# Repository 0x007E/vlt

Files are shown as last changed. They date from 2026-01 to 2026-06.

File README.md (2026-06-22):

  

# `VLT` - Data Vault

The `VLT` is a board with an [RNG90](#additional-information) and a `TRNG` based on a digital circuit. It is possible to generate random numbers and print them over `UART`. The board itself is driven with `5V` over a `USBC` connector. The board itself can be programmed over `USB` and `avr-dude` (`serialupdi`). To programm the board over `USB` (`UART`) it is necessary to enable the `UPDI` programming function (over the onboard dip-switches). 

| Experience  | Level |
|:---|:---:|
| Soldering | ?% |
| Mechanical  | ?% |

# Downloads

| Type | File | Description |
|:---:|:---:|:---|
| Schematic | [pdf](https://github.com/0x007E/vlt/releases/latest/download/schematic.pdf) / [cadlab](https://cadlab.io/project/29805/main/files) | Schematic files |
| Board | [pdf](https://github.com/0x007E/vlt/releases/latest/download/pcb.pdf) / [cadlab](https://cadlab.io/project/29805/main/files) | Board file |
| Drill | [pdf](https://github.com/0x007E/vlt/releases/latest/download/drill.pdf) | Drill file |
| BoM | [xlsx](https://github.com/0x007E/vlt/releases/latest/download/bom.xlsx) / [html](https://github.com/0x007E/vlt/releases/latest/download/ibom.html) | Bill of Material as Excel/interactive HTML |
| PCB | [zip](https://github.com/0x007E/vlt/releases/latest/download/kicad.zip) / [tar](https://github.com/0x007E/vlt/releases/latest/download/kicad.tar.gz) | KiCAD/Gerber/BoM/Drill files |
| Mechanical | [zip](https://github.com/0x007E/vlt/releases/latest/download/freecad.zip) / [tar](https://github.com/0x007E/vlt/releases/latest/download/freecad.tar.gz) | FreeCAD/Housing and PCB (STEP/STL) files |

# Hardware

The pcb is created with `KiCAD`, the housing with `FreeCAD`. All files are built with `github actions` so that they are ready for a production environment.

## PCB

The circuit board is populated on both sides (Top, Bottom). The best way for soldering the `SMD` components is within a vapor phase soldering system and for the `THT` components with a standard soldering system.

### Top Layer

Top Layer

### Bottom Layer

Bottom Layer

## Mechanical

The housing has a tolerance of `0.2mm` on each side of the case. So the pcb should fit perfectly in the housing. The tolerance can be modified with `FreeCAD` in the `Parameter` Spreadsheet.

### Assembled

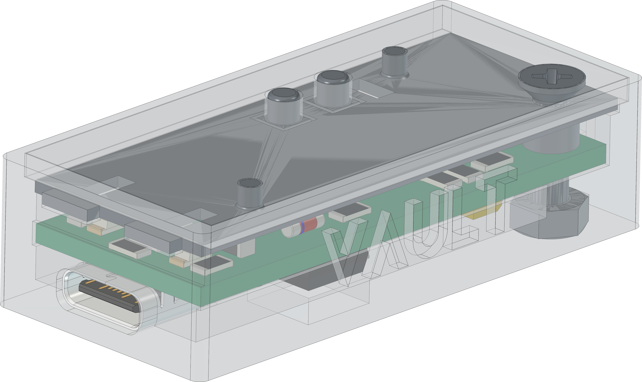
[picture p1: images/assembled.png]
Assembled


### Exploded

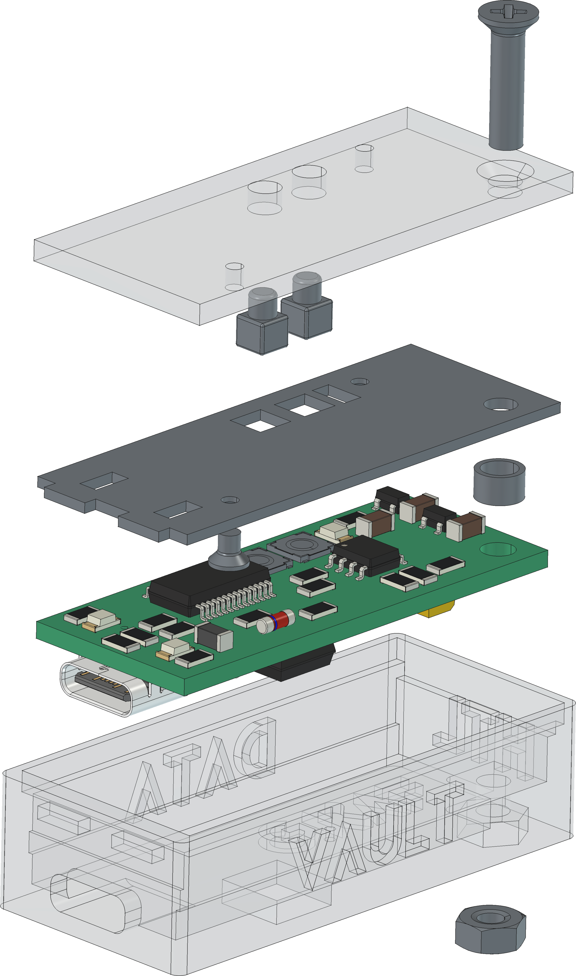
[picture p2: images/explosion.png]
Exploded


# Additional Information

| Type | Link | Description |
|:---:|:---:|:---|
| FT232RL | [pdf](https://ftdichip.com/wp-content/uploads/2020/08/DS_FT232R.pdf) | USB Full Speed to Serial UART IC, Includes Oscillator and EEPROM |
| RNG90 | [pdf](https://ww1.microchip.com/downloads/aemDocuments/documents/SCBU/ProductDocuments/DataSheets/RNG90-CryptoAuthentication-Data-Sheet-DS40002499.pdf) | RNG90 CryptoAuthentication |

---

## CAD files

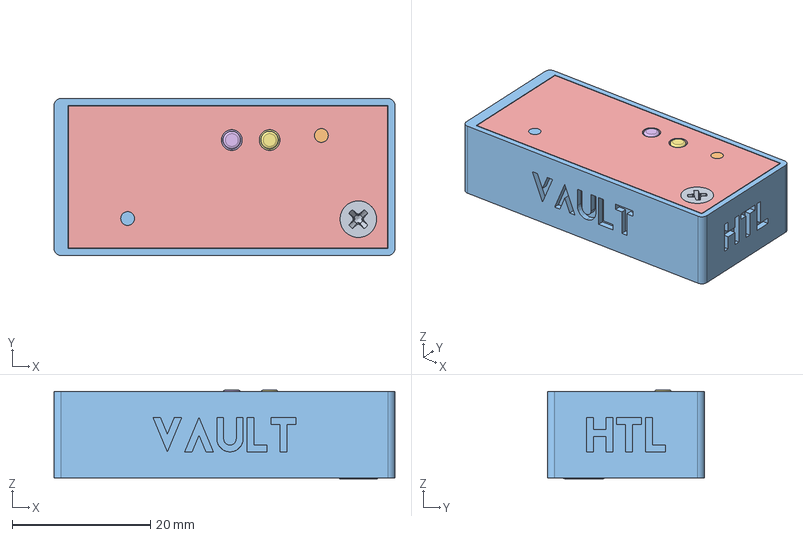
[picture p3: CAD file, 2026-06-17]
mechanical/housing.FCStd
49.3 x 22.7 x 12.8 mm
Pcb_bebe
R1_R_1206_3216Metric_f603423b577c
R5_R_1206_3216Metric_7a7bcd21324c
FB1_L_1206_3216Metric_6fcd3b987292
R15_R_1206_3216Metric_929cc7beda6f
R7_R_1206_3216Metric_0ce5cb771788
R9_R_1206_3216Metric_481f4e21f800
SW1_1_4773eb2bfa41
R17_R_1206_3216Metric_f1ba10fde7b4
D5_LED_1206_3216Metric_f05a8198d155
R4_R_1206_3216Metric_d46e669ba6ba
D3_LED_1206_3216Metric_8bff945b0123
U5_SOT-23-5_21eb59ce2435
R10_R_1206_3216Metric_805d08f095cc
D4_LED_1206_3216Metric_23e95f824b67
R3_R_1206_3216Metric_152a8680d59a
R2_R_1206_3216Metric_31ec9ef0ca55
SW2_1_7b24997decc5
D2_D_MiniMELF_Standard_88843ffb6f9b
C7_C_1206_3216Metric_addbe9d90b21
R6_R_1206_3216Metric_e929d92d168d
R16_R_1206_3216Metric_9d2ac8d5d94a
U6_SOT-23-5_1ebc3b3ece8a
U4_SOIC-8_3.9x4.9mm_P1.27mm_29fbfb699674
R18_R_1206_3216Metric_19b3ebc9aa51
U2_SSOP-28_5.3x10.2mm_P0.65mm_55cecf4e3966
C9_C_1206_3216Metric_460e384975af
R14_R_1206_3216Metric_8825afe39a30
C8_C_1206_3216Metric_d678699426ca
Q2_SOT-23_886c526e182c
U1_SOIC-14_3.9x8.7mm_P1.27mm_801496d5780f
C10_C_1206_3216Metric_e5fbc4a01958
D1_D_MiniMELF_Standard_2ad1a06625b7
C11_C_1206_3216Metric_6c40d3ae1035
C5_C_1206_3216Metric_7fe9f07cf278
C6_C_1206_3216Metric_bb13525eb5cd
C12_C_1206_3216Metric_136c5c0d3721
U3_SOIC-8_3.9x4.9mm_P1.27mm_efde70a0c48e
SW3_SW_DIP_SPSTx02_Slide_67x664mm_W861mm_P254mm_LowProfile_263cb1406708
R8_R_1206_3216Metric_50ab7bc52720
C1_CP_EIA_3528_21_Kemet_B_45d5b020196d
USB4110-GF-A_PART1
C3_C_1206_3216Metric_4fc889ddf598
C4_C_1206_3216Metric_7ddc56e0882d
R12_R_1206_3216Metric_526ac6653cee
C2_CP_EIA_3528_21_Kemet_B_2a68fe3d668e
C13_C_1206_3216Metric_76a50684b00a
U7_SOT-23-5_5363ef70f895
R20_R_1206_3216Metric_7691531cec22
R19_R_1206_3216Metric_f297b9b6c010
Case
Aluminium
Acrylglass
Count
Enter
M3-Nut
M3x12.5-Screw
M2x3-Screw
M2x3-Screw001
Spacer

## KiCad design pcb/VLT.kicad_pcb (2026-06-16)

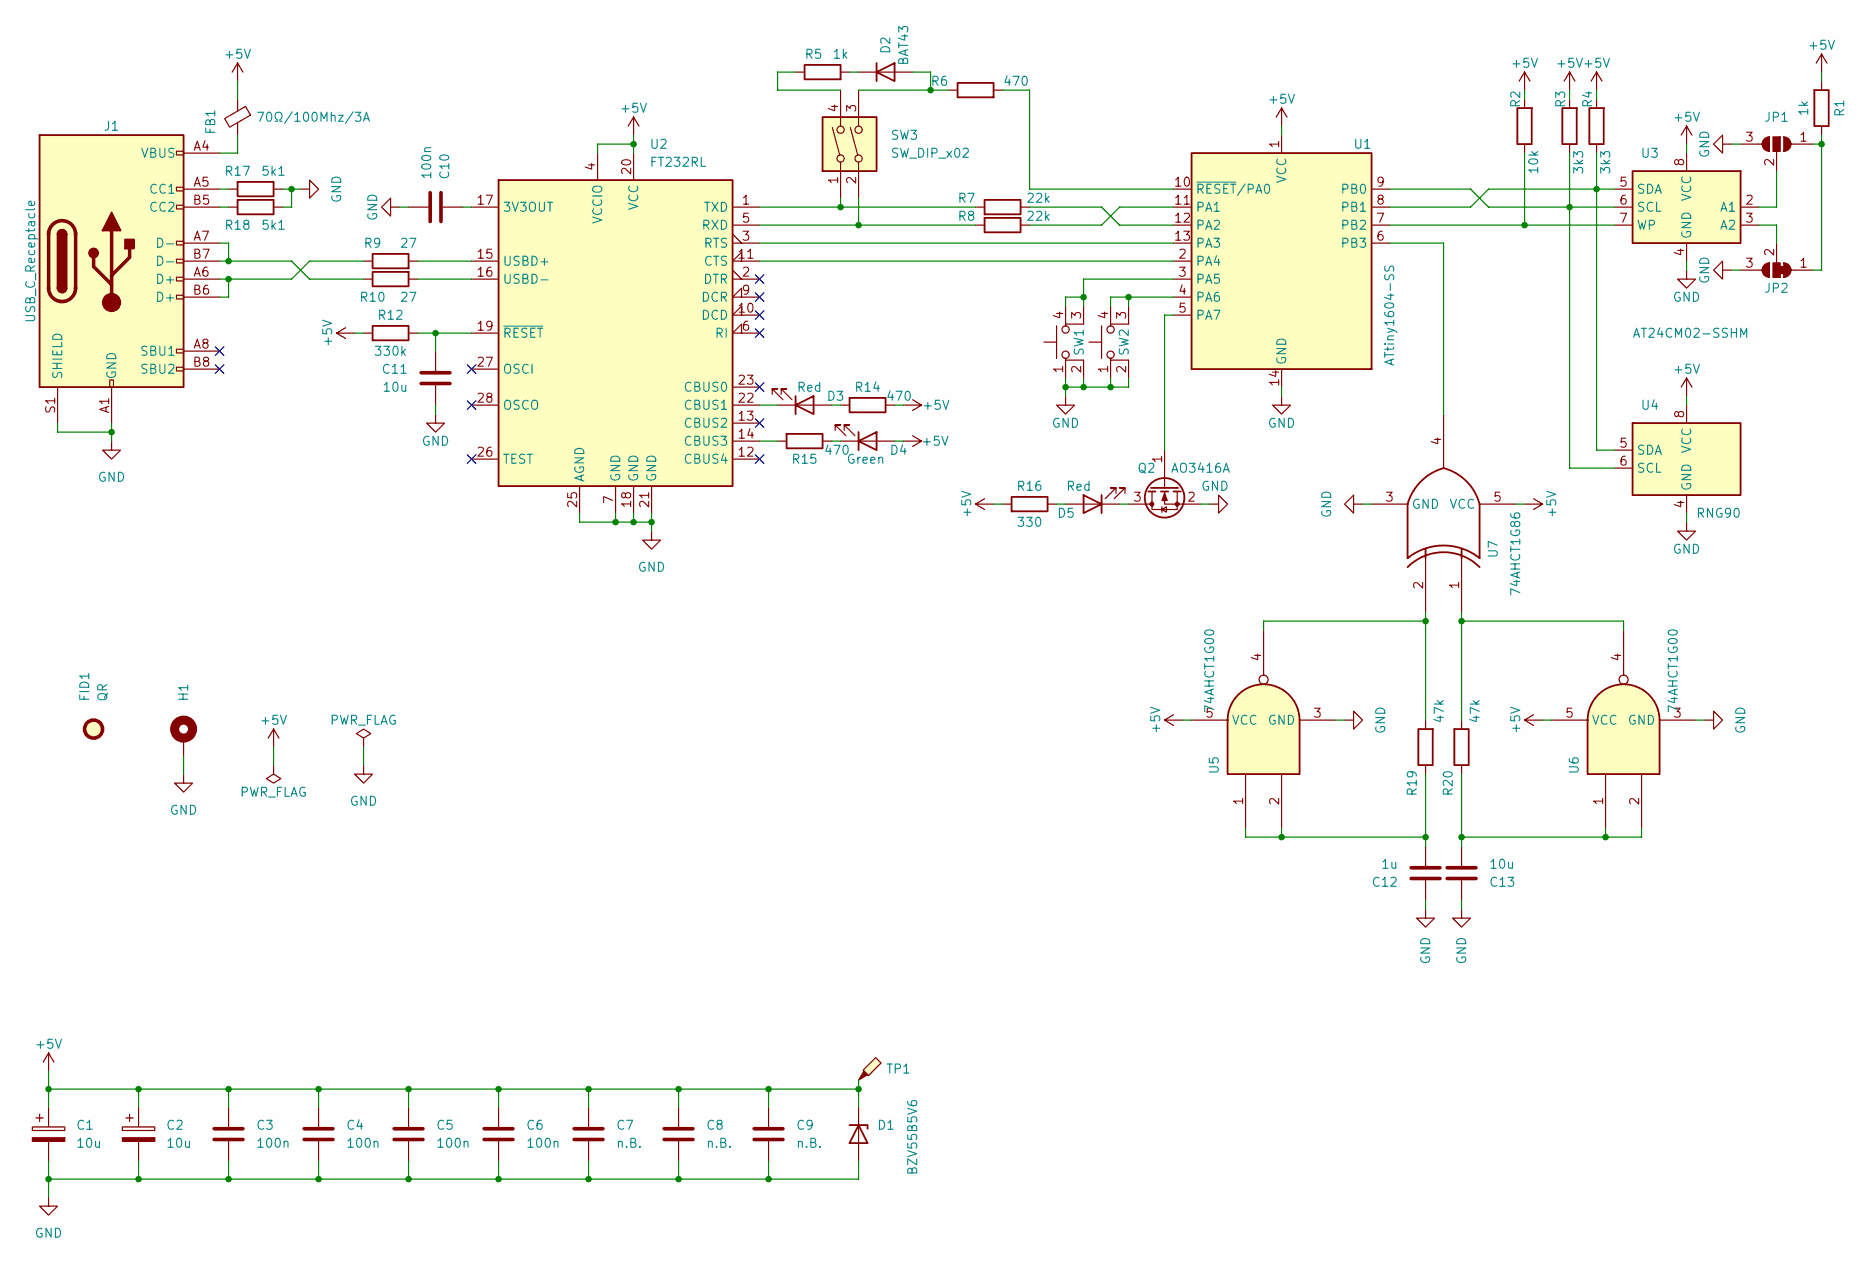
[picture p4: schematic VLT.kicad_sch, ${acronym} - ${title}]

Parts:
C1, C2: 10u; CP_EIA-3528-21_Kemet-B
C3, C4, C5, C6, C10: 100n; C_1206_3216Metric
C7, C8, C9: n.B.; C_1206_3216Metric
C11, C13: 10u; C_1206_3216Metric
C12: 1u; C_1206_3216Metric
D1: BZV55B5V6; D_MiniMELF
D2: BAT43; D_MiniMELF
D3, D5: Red; LED_1206_3216Metric
D4: Green; LED_1206_3216Metric
FB1: 70Ω/100Mhz/3A; L_1206_3216Metric
FID1: QR; QR_0x007e_very_small
H1: MountingHole_Pad; MountingHole_3.2mm_M3_DIN965_Pad
J1: USB_C_Receptacle; USB_C_Receptacle_GCT_USB4110
JP1: SolderJumper_3_Open; SolderJumper-3_P1.3mm_Open_RoundedPad1.0x1.5mm
JP2: SolderJumper_3_Bridged12; SolderJumper-3_P1.3mm_Bridged12_RoundedPad1.0x1.5mm
Q2: AO3416A; SOT-23
R1, R5: 1k; R_1206_3216Metric
R2: 10k; R_1206_3216Metric
R3, R4: 3k3; R_1206_3216Metric
R6, R14, R15: 470; R_1206_3216Metric
R7, R8: 22k; R_1206_3216Metric
R9, R10: 27; R_1206_3216Metric
R12: 330k; R_1206_3216Metric
R16: 330; R_1206_3216Metric
R17, R18: 5k1; R_1206_3216Metric
R19, R20: 47k; R_1206_3216Metric
SW1, SW2: SW_MEC_5E; SW_PTS530_GK055_SMTR_LFS
SW3: SW_DIP_x02; SW_DIP_SPSTx02_Slide_6.7x6.64mm_W8.61mm_P2.54mm_LowProfile
TP1: TestPoint_Probe; TestPoint_Pad_D1.0mm
U1: ATtiny1604-SS; SOIC-14_3.9x8.7mm_P1.27mm
U2: FT232RL; SSOP-28_5.3x10.2mm_P0.65mm
U3: AT24CM02-SSHM; SOIC-8_3.9x4.9mm_P1.27mm
U4: RNG90; SOIC-8_3.9x4.9mm_P1.27mm
U5, U6: 74AHCT1G00; SOT-23-5
U7: 74AHCT1G86; SOT-23-5

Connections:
+5V: C1.1, C2.1, C3.1, C4.1, C5.1, C6.1, C7.1, C8.1, C9.1, D1.1 (K), D4.2 (A), FB1.1, R1.2, R2.2, R3.2, R4.2, R12.2, R14.1, R16.2, TP1.1, U1.1 (VCC), U2.4 (VCCIO), U2.20 (VCC), U3.8 (VCC), U4.8 (VCC), U5.5 (VCC), U6.5 (VCC), U7.5 (VCC)
GND: C1.2, C2.2, C3.2, C4.2, C5.2, C6.2, C7.2, C8.2, C9.2, C10.1, C11.2, C12.1, C13.1, D1.2 (A), H1.1, J1.A1 (GND), J1.A12 (GND), J1.B1 (GND), J1.B12 (GND), J1.S1 (SHIELD), JP1.3 (B), JP2.3 (B), Q2.2 (S), R17.1, R18.1, SW1.1, SW1.2, SW2.1, SW2.2, U1.14 (GND), U2.7 (GND), U2.18 (GND), U2.21 (GND), U2.25 (AGND), U3.4 (GND), U4.4 (GND), U5.3 (GND), U6.3 (GND), U7.3 (GND)
unnamed: C12.2, R19.1, U5.1, U5.2
unnamed: C13.2, R20.1, U6.1, U6.2
unnamed: D2.2 (A), R6.1, SW3.3
unnamed: D2.1 (K), R5.2
unnamed: D3.2 (A), R14.2
unnamed: D3.1 (K), U2.22 (CBUS1)
unnamed: D4.1 (K), R15.1
unnamed: D5.2 (A), R16.1
unnamed: D5.1 (K), Q2.3 (D)
unnamed: FB1.2, J1.A4 (VBUS), J1.A9 (VBUS), J1.B4 (VBUS), J1.B9 (VBUS)
unnamed: J1.A5 (CC1), R17.2
unnamed: J1.B5 (CC2), R18.2
unnamed: J1.A6 (D+), J1.B6 (D+), R9.1
unnamed: J1.A7 (D-), J1.B7 (D-), R10.1
unnamed: JP1.1 (A), JP2.1 (A), R1.1
unnamed: JP1.2 (C), U3.2 (A1)
unnamed: JP2.2 (C), U3.3 (A2)
unnamed: Q2.1 (G), U1.5 (PA7)
unnamed: R5.1, SW3.4
unnamed: R19.2, U5.4, U7.2
unnamed: R20.2, U6.4, U7.1
unnamed: SW1.3 (K), SW1.4 (A), U1.3 (PA5)
unnamed: SW2.3 (K), SW2.4 (A), U1.4 (PA6)
unnamed: R8.1, U1.11 (PA1)
unnamed: R7.1, U1.12 (PA2)
unnamed: U1.13 (PA3), U2.3 (RTS)
unnamed: U1.2 (PA4), U2.11 (CTS)
unnamed: R3.1, U1.9 (PB0), U3.6 (SCL), U4.6 (SCL)
unnamed: R4.1, U1.8 (PB1), U3.5 (SDA), U4.5 (SDA)
unnamed: R2.1, U1.7 (PB2), U3.7 (WP)
unnamed: U1.6 (PB3), U7.4
unnamed: R6.2, U1.10 (~RESET/PA0)
unnamed: C10.2, U2.17 (3V3OUT)
unnamed: R15.2, U2.14 (CBUS3)
unnamed: R8.2, SW3.2, U2.5 (RXD)
unnamed: R7.2, SW3.1, U2.1 (TXD)
unnamed: R9.2, U2.15 (USBD+)
unnamed: R10.2, U2.16 (USBD-)
unnamed: C11.1, R12.1, U2.19 (~RESET)

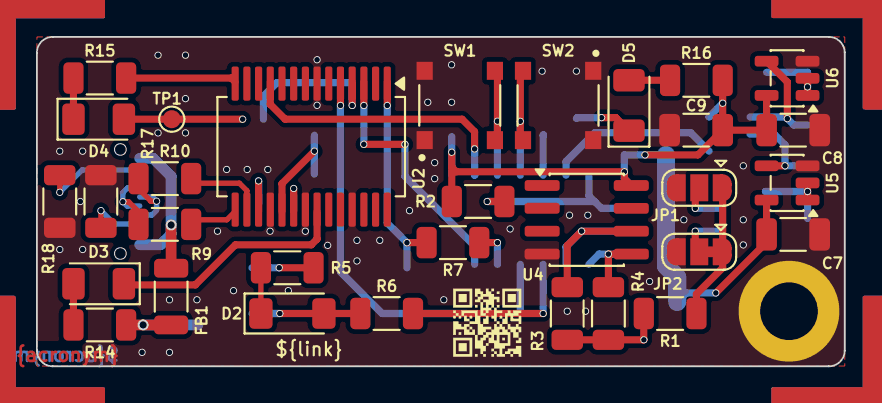
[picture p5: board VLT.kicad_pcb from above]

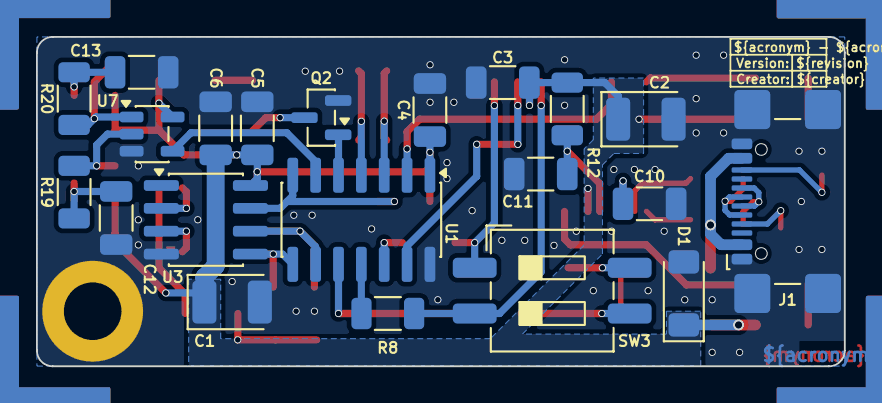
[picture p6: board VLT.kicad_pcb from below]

Board: 2 copper layers, 44.9 x 18.3 mm, 54 parts (21 on the bottom side), 41 nets.

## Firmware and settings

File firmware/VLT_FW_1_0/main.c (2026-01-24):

#include "main.h"

unsigned char EEMEM ee_project[] = "\n\rVLT - Data Vault\n\r";
unsigned char EEMEM ee_creator[] = "Author: Ing. Raffael GAECHTER";
unsigned char EEMEM ee_copyright[] = "(c) 2026, All rights reserved!";
unsigned char EEMEM ee_version = 0x10;

unsigned char EEMEM ee_masterkey[] = "Master Key: ";

SYSTICK_Timer systick_timer;
char buffer[100];

enum BYTE_Nibble_t
{
	BYTE_Nibble_Low=0,
	BYTE_Nibble_High
};
typedef enum BYTE_Nibble_t BYTE_Nibble;

ISR(RTC_CNT_vect)
{
	systick_tick();
	RTC.INTFLAGS = RTC_OVF_bm;
}

ISR(TCA0_OVF_vect)
{
	trng_next_bit(TRNG_PORT.IN & TRNG_PIN);
	TCA0.SINGLE.INTFLAGS = TCA_SINGLE_OVF_bm;
}

void systick_timer_wait_ms(unsigned int ms)
{
	systick_timer_wait(ms);
}

void at24cm0x_wp(AT24CM0X_WP_Mode mode)
{
	if(mode)
	{
		AT24CM0X_PORT_WP.DIRSET = AT24CM0X_PIN_WP;
		AT24CM0X_PORT_WP.OUTCLR = AT24CM0X_PIN_WP;
		return;
	}
	AT24CM0X_PORT_WP.DIRCLR = AT24CM0X_PIN_WP;
}

static void trng_start(void)
{
	TRNG_PORT.DIRCLR = TRNG_PIN;
	TRNG_PORT.TRNG_PIN_PINCTRL = TRNG_PIN_SETUP;
	
	TCA0.SINGLE.PER = 0x0085;
	TCA0.SINGLE.INTCTRL = TCA_SINGLE_OVF_bm;
	TCA0.SINGLE.CTRLA = TCA_SINGLE_CLKSEL_DIV1_gc | TCA_SINGLE_ENABLE_bm;
}

static void trng_stop(void)
{
	TCA0.SINGLE.INTCTRL = TCA_SINGLE_OVF_bm;
	TCA0.SINGLE.CTRLA &=  ~TCA_SINGLE_ENABLE_bm;
}

int main(void)
{
	system_init();
	rtc_init();
	sei();
	
	systick_init();
	uart_init();
	twi_init();
	input_init();
	
	trng_init();
	trng_start();
	trng_stop();
	
	rng90_init();
	
	at24cm0x_init();
	
	PORTA.DIRSET = PIN7_bm;

	while(!input_status(INPUT_SW1))
	{
		PORTA.OUTTGL = PIN7_bm;
		systick_timer_wait_ms(250UL);
	}

	systick_timer_wait_ms(500UL);
	PORTA.OUTCLR = PIN7_bm;
	
	console_clear();
	
	eeprom_read_block(buffer, ee_project, sizeof(ee_project));
	printf("%sVersion: %1u.%1u", buffer, (eeprom_read_byte(&ee_version)>>4), (0x0F & eeprom_read_byte(&ee_version)));
	console_line(40);
	eeprom_read_block(buffer, ee_creator, sizeof(ee_creator));
	printf("%s", buffer);
	console_newline();
	eeprom_read_block(buffer, ee_copyright, sizeof(ee_copyright));
	printf("%s", buffer);
	console_line(40);
	eeprom_read_block(buffer, ee_masterkey, sizeof(ee_masterkey));
	printf("%s", buffer);
	
	unsigned char i = 0;
	unsigned char run = 1;
	
	BYTE_Nibble nibble = BYTE_Nibble_High;
	
	buffer[i] = '\0';
	
	do 
	{
		if(uart_scanchar(&buffer[i]) == UART_Received)
		{
			if(buffer[i] == '\n' || buffer[i] == '\r')
			{
				break;
			}
			uart_putchar('*');
			i++;
		}
		else if(input_status(INPUT_SW1))
		{
			systick_timer_wait_ms(250UL);
			
			if(nibble == BYTE_Nibble_High)
			{
				buffer[i] = buffer[i] + 0x10;
			}
			else if(nibble == BYTE_Nibble_Low)
			{
				buffer[i] = buffer[i] + 0x01;
			}
			
			if(	(nibble == BYTE_Nibble_Low) && 
				((buffer[i] < ' ') || 
				(buffer[i] > '~')))
			{
				printf("Error -> Restarting\n\r");
				
				// Restart System
				CCP = CCP_IOREG_gc;
				RSTCTRL.SWRR = RSTCTRL_SWRE_bm;

				PORTA.INTFLAGS = PORT_INT_6_bm;
			}
			
			while(input_status(INPUT_SW1))
			{
				PORTA.OUTSET = PIN7_bm;
			}
			
		}
		else if(input_status(INPUT_SW2))
		{
			systick_timer_wait_ms(10UL);
			
			if(nibble == BYTE_Nibble_High)
			{
				nibble = BYTE_Nibble_Low;
			}
			else
			{
				uart_putchar('*');
				buffer[(++i)] = '\0';
				nibble = BYTE_Nibble_High;
			}
			
			systick_timer_set(&systick_timer, 2000UL);
			
			while(input_status(INPUT_SW2))
			{
				PORTA.OUTSET = PIN7_bm;
				
				if(systick_timer_elapsed(&systick_timer) && nibble == BYTE_Nibble_High)
				{
					run = 0;
					break;
				}
			}
		}
		PORTA.OUTCLR = PIN7_bm;
		
		systick_timer_wait_ms(10UL);
		
	} while (run);
	
	PORTA.OUTCLR = PIN7_bm;
	buffer[i] = '\0';
	
	console_newline();
	
	printf("\n\rPhrase: %s\n\r", buffer);
	
	while(1)
	{
		systick_timer_wait_ms(1000UL);
		
		// Restart System
		CCP = CCP_IOREG_gc;
		RSTCTRL.SWRR = RSTCTRL_SWRE_bm;

		PORTA.INTFLAGS = PORT_INT_6_bm;
	}
}

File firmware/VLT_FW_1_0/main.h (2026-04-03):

#ifndef MAIN_H_
#define MAIN_H_

	// !!!!!!!!!!!!!!!!!!!!!!!!!!!!!!!
	// !! SETUP GLOBAL DEFINES      !!
	// !!!!!!!!!!!!!!!!!!!!!!!!!!!!!!!
	// !! UART_RXC_ECHO             !!
	// !! AT24CM0X_WP_CONTROL_EN    !!
	// !!!!!!!!!!!!!!!!!!!!!!!!!!!!!!!

	#ifndef F_CPU
		#define F_CPU 20000000UL
	#endif
	
	#define IO_PORT PORTA
	#define LED PIN7_bm

	#ifndef TRNG_PORT
		#define TRNG_PORT PORTB
	#endif

	#ifndef TRNG_PIN
		#define TRNG_PIN         SET_PIN(3, _bm)
		#define TRNG_PIN_PINCTRL SET_PIN(3, CTRL)
		#define TRNG_PIN_SETUP   PORT_PULLUPEN_bm
	#endif

	#define AT24CM0X_PORT_WP PORTB
	#define AT24CM0X_PIN_WP PIN2_bm

	#include <string.h>
	#include <avr/io.h>
	#include <avr/eeprom.h>
	#include <avr/interrupt.h>

	#include "../lib/hal/avr0/system/system.h"
	#include "../lib/hal/avr0/rtc/rtc.h"
	#include "../lib/hal/avr0/input/input.h"
	#include "../lib/hal/avr0/uart/uart.h"
	#include "../lib/hal/avr0/twi/twi.h"

	#include "../lib/drivers/crypto/trng/trng.h"
	#include "../lib/drivers/crypto/rng90/rng90.h"
	#include "../lib/drivers/prom/at24cm0x/at24cm0x.h"
	
	#include "../lib/utils/systick/systick.h"
	#include "../lib/utils/console/console.h"
	
#endif /* MAIN_H_ */

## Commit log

2025-12-17 Add pcb layout
    [VLT.kicad_pcb, VLT.kicad_sch]
2025-12-17 Add mechanical parts
    [housing.FCStd]
2026-01-03 Change partlist vendors
    [VLT.kicad_pcb, VLT.kicad_sch]
2026-01-22 Adapt values for rng
    [VLT.kicad_pcb, VLT.kicad_sch]
2026-01-24 Disable uart rxc echo
2026-04-09 Optimize fabrication layer
    [VLT.kicad_pcb]
2026-06-16 Update to KiCAD 9
    [VLT.kicad_pcb, VLT.kicad_sch]
2026-06-16 Rename/Add/Remove bom fields
    [VLT.kicad_pcb, VLT.kicad_sch]
2026-06-16 Optimize assembly explosion
    [housing.FCStd]
2026-06-17 Add adapted pcb layout
    [housing.FCStd]
2026-06-22 Add missing values in bom

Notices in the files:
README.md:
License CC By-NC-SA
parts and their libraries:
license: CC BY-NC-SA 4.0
